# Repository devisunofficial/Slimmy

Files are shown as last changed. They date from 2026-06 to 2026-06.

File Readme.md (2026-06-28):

# Slimmy

Slimmy is a Unidirectional USB 3.0 TF-Card Reader.
1. Why I made this?
   Because I wanted to make Type-C USB 3.0 device.
2. Why Unidirectional?
   Routing biderctional Type-C is difficult(atleast for me) and it would further increase the fabrication cost

### Features:

 - USB 3.0 TF-Card Reader
 - True USB 3.0 controller is used

### CAD Model:
Even though there is no Case or anything, here is PCB in 3d View
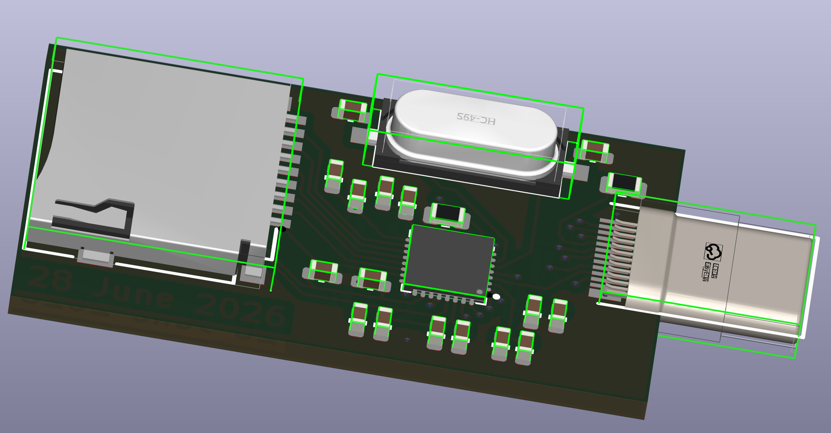
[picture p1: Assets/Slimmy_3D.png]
Hub-3D


### PCB:
Here's my PCB! It was made in KiCad. 

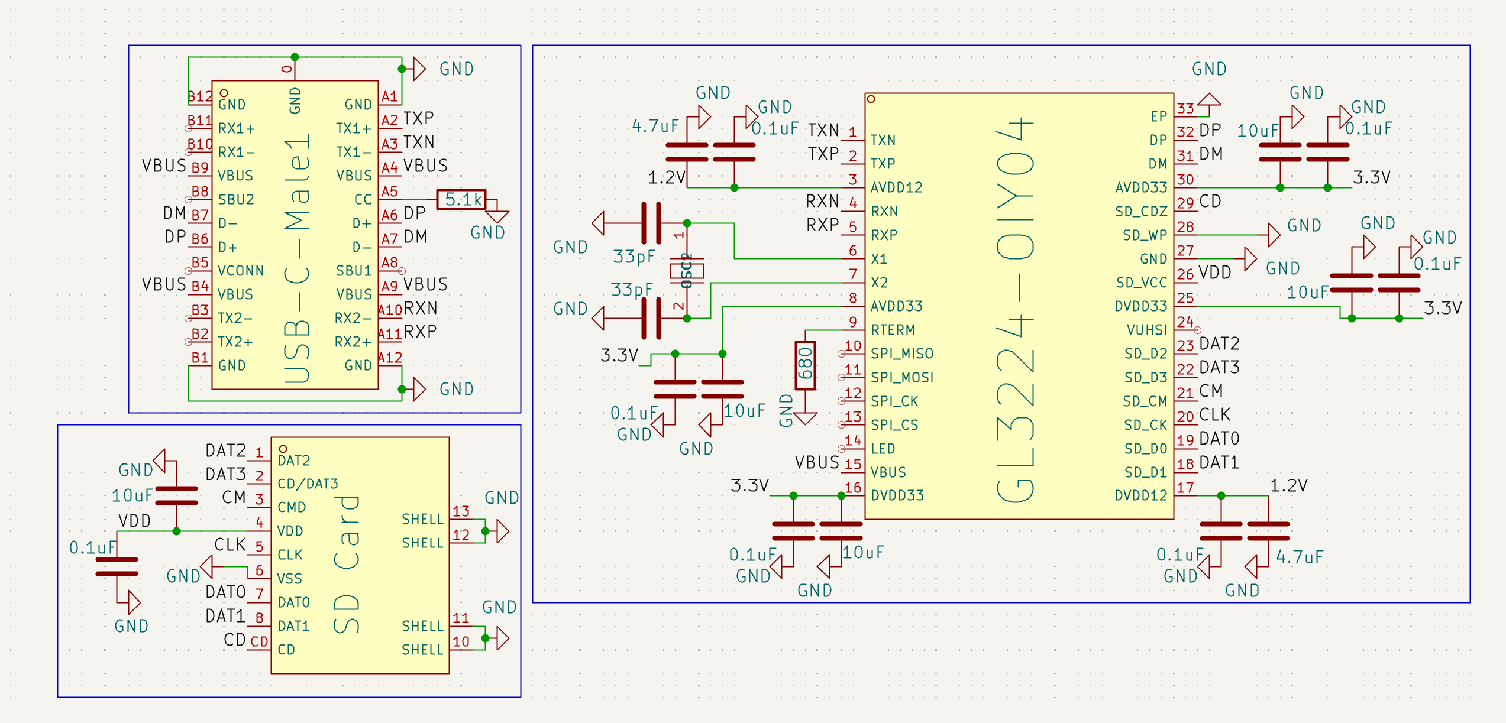
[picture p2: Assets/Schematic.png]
Schematic : 
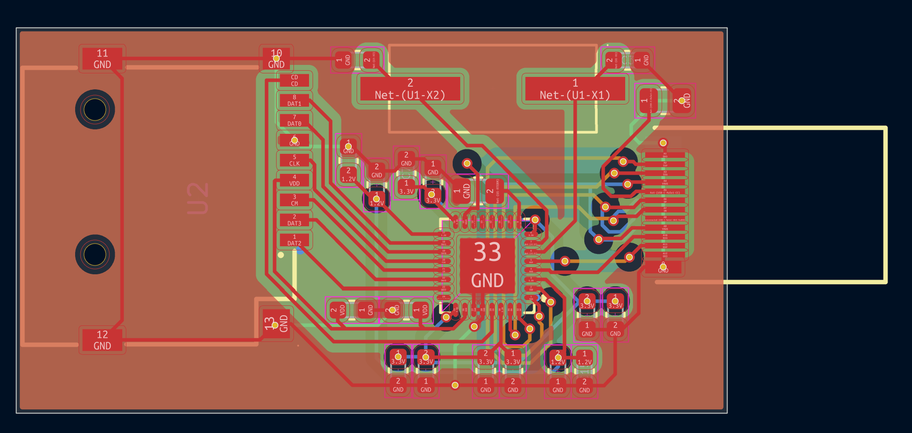
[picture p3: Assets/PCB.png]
PCB Footprint : 

### Firmware Overview:
No FIRMWARE ;)

### Assembly :
Done By JLCPCB because I don't have Hot plate!!

### BOM Table
|Name|Use|Quantity|Distributer|
|-----|---|---|---|
|GL3224-OIY04|USB Hub Controller|1|JLCPCB|
|PCB|Main-Circuit|1|JLCPCB|
|USB-C|Up-Stream Port|1|JLCPCB|
|TF Card|I don't have TF Card to use USB 3.0|1|Amazon|

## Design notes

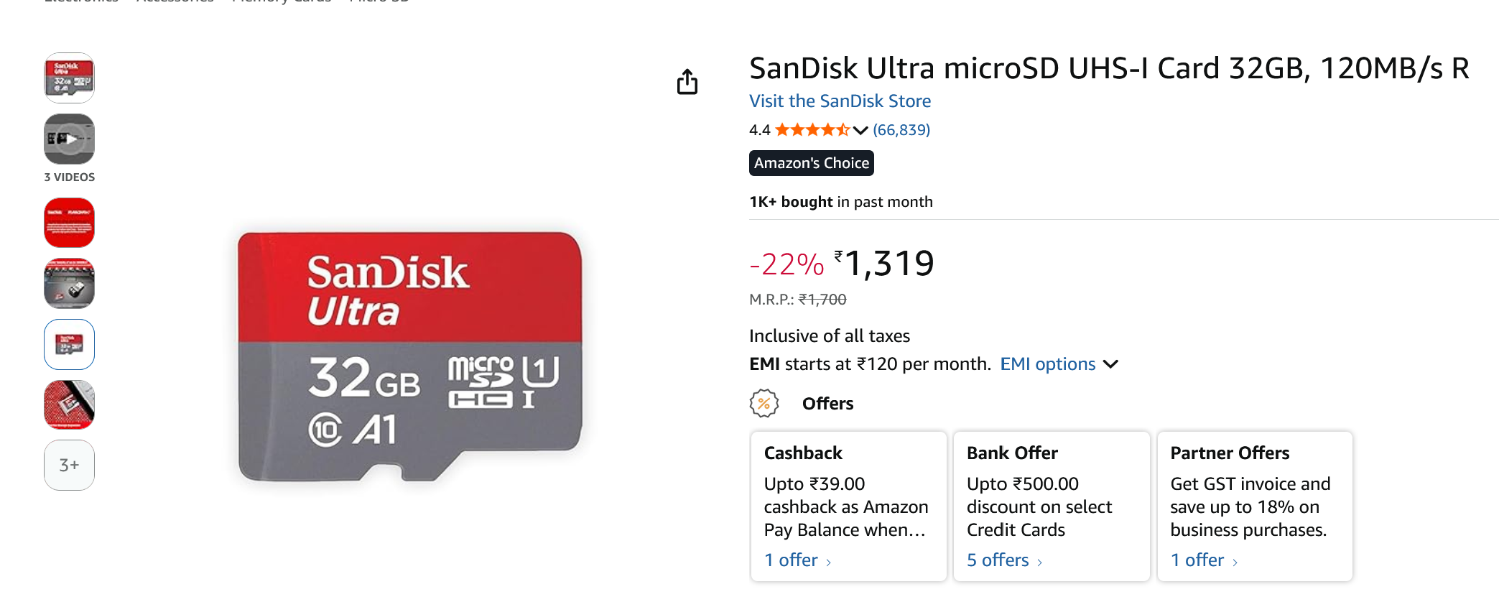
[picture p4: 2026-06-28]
JLCPCB/Screenshot 2026-06-28 103536.png

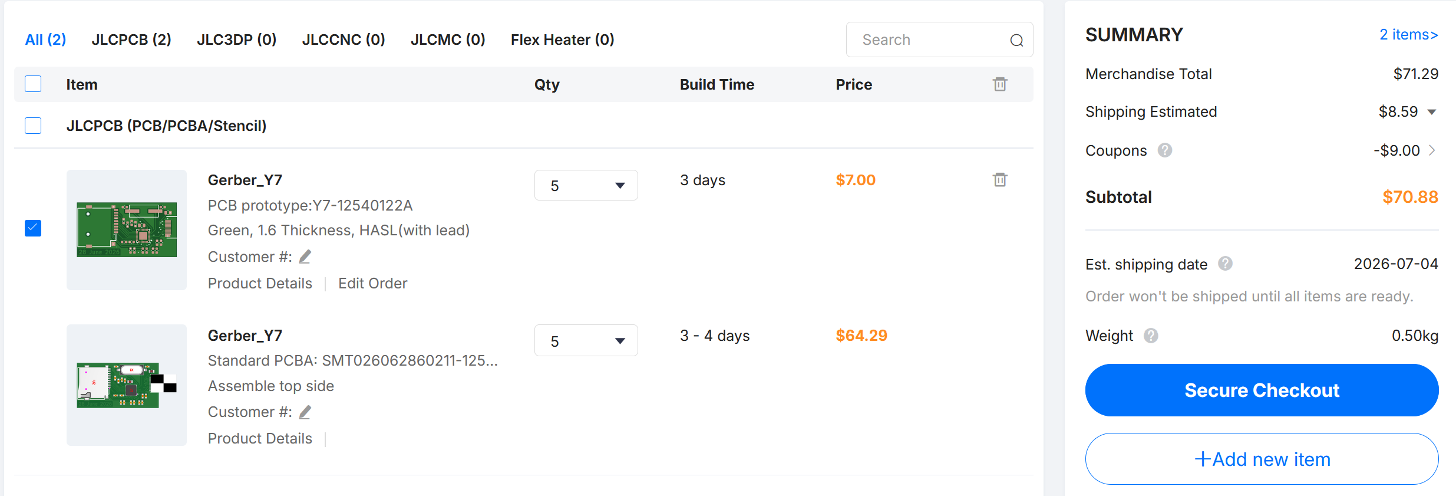
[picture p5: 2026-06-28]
JLCPCB/Cart-Screenshot.png

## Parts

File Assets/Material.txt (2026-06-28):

1. Male Type C (C530606)
2. GL3224-OIY04 (Controller Board)
3. SD Card Reader (C5184837)

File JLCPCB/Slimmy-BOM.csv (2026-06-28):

Comment | Designator | Footprint
0.1uF | C1, C6, C7, C9, C11, C13, C15 | C_0603_1608Metric
10uF | C2, C5, C8, C10, C12 | C_0603_1608Metric
33pF | C3, C4 | C_0603_1608Metric
4.7uF | C14, C16 | C_0603_1608Metric
5.1k | R1 | R_0805_2012Metric
680 | R2 | R_0805_2012Metric
GL3224-OIY04 | U1 | C157357_HQFN-32_L5_0-W5_0-P0_50-BL-EP3_0
SD Card | U2 | C5184837_TF-SMD_TF-PUSH
TYPE-C-31-G-02 | USB-C-Male1 | C530606_USB-C-SMD_TYPE-C-31-G-02
HC-49SMD 25MHZ 20PF 20PPM | X1 | C14872_HC-49S_L11_4-W4_8

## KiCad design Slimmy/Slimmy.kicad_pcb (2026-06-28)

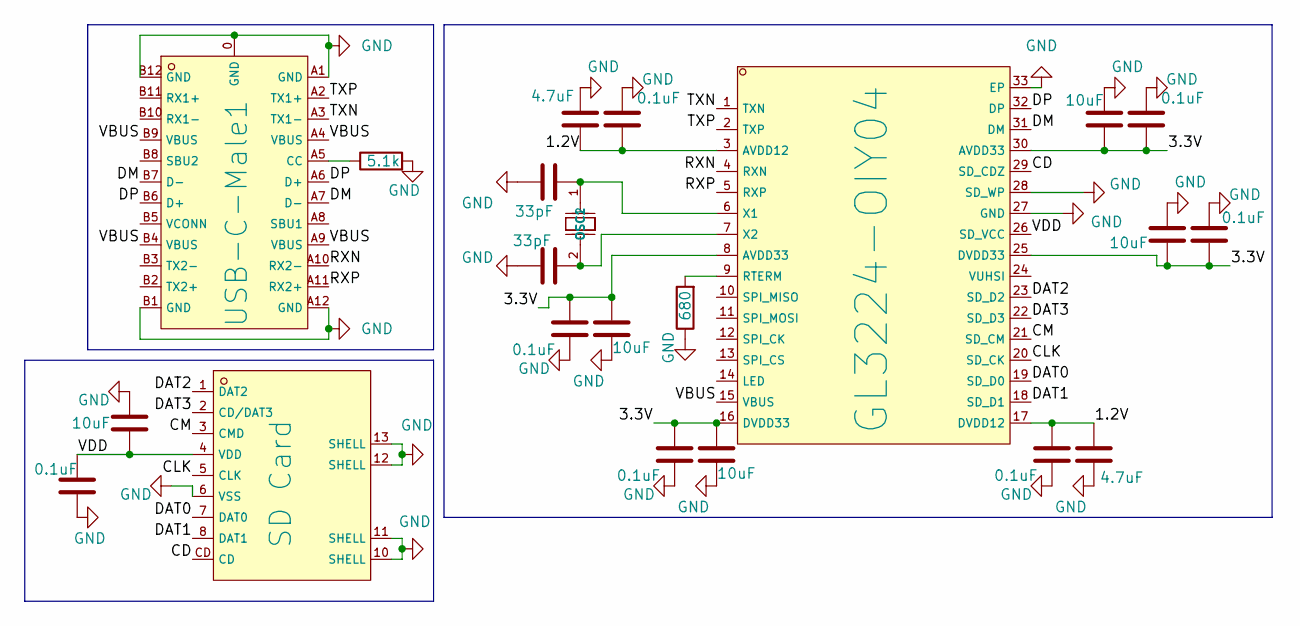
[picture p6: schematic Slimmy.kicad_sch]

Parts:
C1, C6, C7, C9, C11, C13, C15: 0.1uF; C_0603_1608Metric
C2, C5, C8, C10, C12: 10uF; C_0603_1608Metric
C3, C4: 33pF; C_0603_1608Metric
C14, C16: 4.7uF; C_0603_1608Metric
R1: 5.1k; R_0805_2012Metric
R2: 680; R_0805_2012Metric
U1: GL3224-OIY04; C157357_HQFN-32_L5_0-W5_0-P0_50-BL-EP3_0; LCSC C157357
U2: SD Card; C5184837_TF-SMD_TF-PUSH; LCSC C5184837
USB-C-Male1: TYPE-C-31-G-02; C530606_USB-C-SMD_TYPE-C-31-G-02; LCSC C530606
X1: HC-49SMD 25MHZ 20PF 20PPM; C14872_HC-49S_L11_4-W4_8; LCSC C14872

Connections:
/1.2V: C13.1, C14.2, C15.1, C16.2, U1.3 (AVDD12), U1.17 (DVDD12)
/3.3V: C5.2, C6.1, C7.1, C8.2, C9.1, C10.2, C11.1, C12.2, U1.8 (AVDD33), U1.16 (DVDD33), U1.25 (DVDD33), U1.30 (AVDD33)
/CD: U1.29 (SD_CDZ), U2.CD
/CLK: U1.20 (SD_CK), U2.5 (CLK)
/CM: U1.21 (SD_CM), U2.3 (CMD)
/DAT0: U1.19 (SD_D0), U2.7 (DAT0)
/DAT1: U1.18 (SD_D1), U2.8 (DAT1)
/DAT2: U1.23 (SD_D2), U2.1 (DAT2)
/DAT3: U1.22 (SD_D3), U2.2 (CD/DAT3)
/DM: U1.31 (DM), USB-C-Male1.A7 (D-), USB-C-Male1.B7 (D-)
/DP: U1.32 (DP), USB-C-Male1.A6 (D+), USB-C-Male1.B6 (D+)
/RXN: U1.4 (RXN), USB-C-Male1.A10 (RX2-)
/RXP: U1.5 (RXP), USB-C-Male1.A11 (RX2+)
/TXN: U1.1 (TXN), USB-C-Male1.A3 (TX1-)
/TXP: U1.2 (TXP), USB-C-Male1.A2 (TX1+)
/VBUS: U1.15 (VBUS), USB-C-Male1.A4 (VBUS), USB-C-Male1.A9 (VBUS), USB-C-Male1.B4 (VBUS), USB-C-Male1.B9 (VBUS)
/VDD: C1.1, C2.2, U1.26 (SD_VCC), U2.4 (VDD)
GND: C1.2, C2.1, C3.1, C4.1, C5.1, C6.2, C7.2, C8.1, C9.2, C10.1, C11.2, C12.1, C13.2, C14.1, C15.2, C16.1, R1.2, R2.1, U1.27 (GND), U1.28 (SD_WP), U1.33 (EP), U2.6 (VSS), U2.10 (SHELL), U2.11 (SHELL), U2.12 (SHELL), U2.13 (SHELL), USB-C-Male1.0 (GND), USB-C-Male1.A1 (GND), USB-C-Male1.A12 (GND), USB-C-Male1.B1 (GND), USB-C-Male1.B12 (GND)
unnamed: R2.2, U1.9 (RTERM)
unnamed: C3.2, U1.6 (X1), X1.1 (OSC1)
unnamed: C4.2, U1.7 (X2), X1.2 (OSC2)
unnamed: R1.1, USB-C-Male1.A5 (CC)

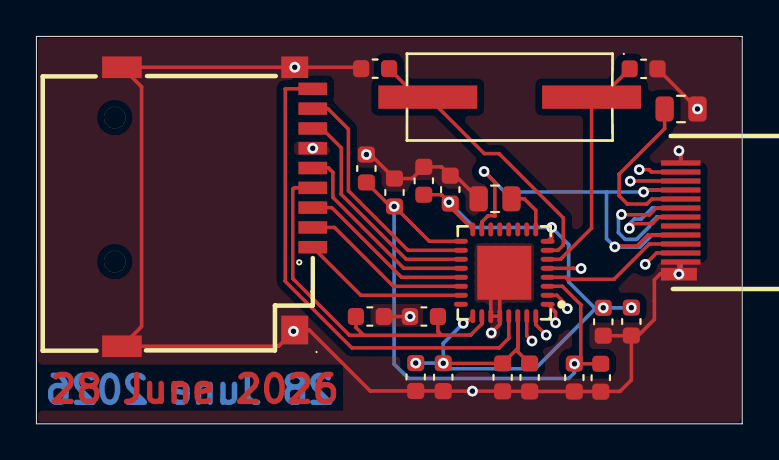
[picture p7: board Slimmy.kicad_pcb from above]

Board: 4 copper layers, 39.2 x 21.5 mm, 22 parts (0 on the bottom side), 22 nets.
